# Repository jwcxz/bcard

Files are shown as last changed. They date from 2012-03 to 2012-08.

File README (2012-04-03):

bcard

http://jwcxz.com/projects/bcard

bcard is an experimental attempt to make cheap electronic business card on a
thin PCB.  The main goals are for it to be:

    - cheap
    - not gaudy
    - not stupid
    
As awesome as it would be to make the card appear as a USB flash device that
contains my resume, that would be a bit too expensive.  One alternative, is
this design:

    http://www.instructables.com/id/USB-PCB-Business-Card/
    
But somebody already made it :) Other designs are much more expensive.

    http://mikepuchol.com/my-pcb-business-card/
    http://electronoblog.allanw.org/2011/08/yet-another-pcb-business-card-with-touchpad/
    http://www.youtube.com/watch?v=gSN2SAgYy7M
    http://www.chasingtrons.com/main/tag/business-card
    
My design incorporates a capacitive touch sensor with some blue LEDs around the
corners.  The blue LEDs are actually mounted upside-down so that the card
fluoresces.

Cost of parts is about $1.80 in quantities of 25 (at Digi-Key prices).  At
quantities of 100, the cost per board is $1.54.  The majority of the cost is in
the 4 LEDs and the microcontroller.  You can shave off a few cents by going
with an ATTiny4 instead of an ATTiny10.

IDK, it's cute.

Software Used:
    Board Design: Kicad     http://kicad.sf.net
                  Inkscape  http://inkscape.org
    Firwmare:     AVRA      http://avra.sf.net
                  AVRDUDE   http://www.nongnu.org/avrdude/

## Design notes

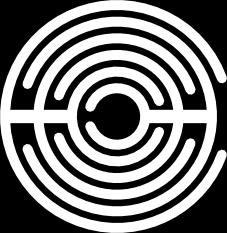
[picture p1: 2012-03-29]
imprint/sense.png

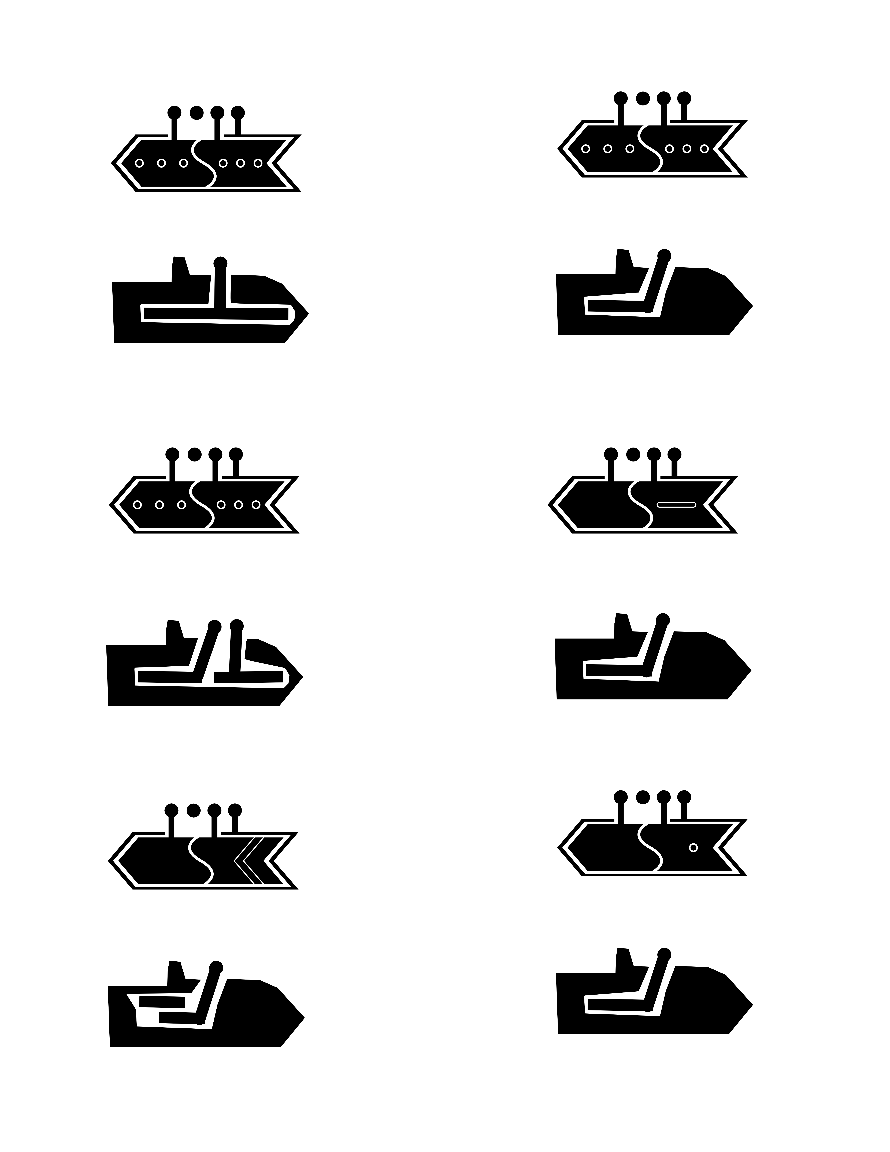
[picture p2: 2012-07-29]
boards/csensetests/csensetests2.png

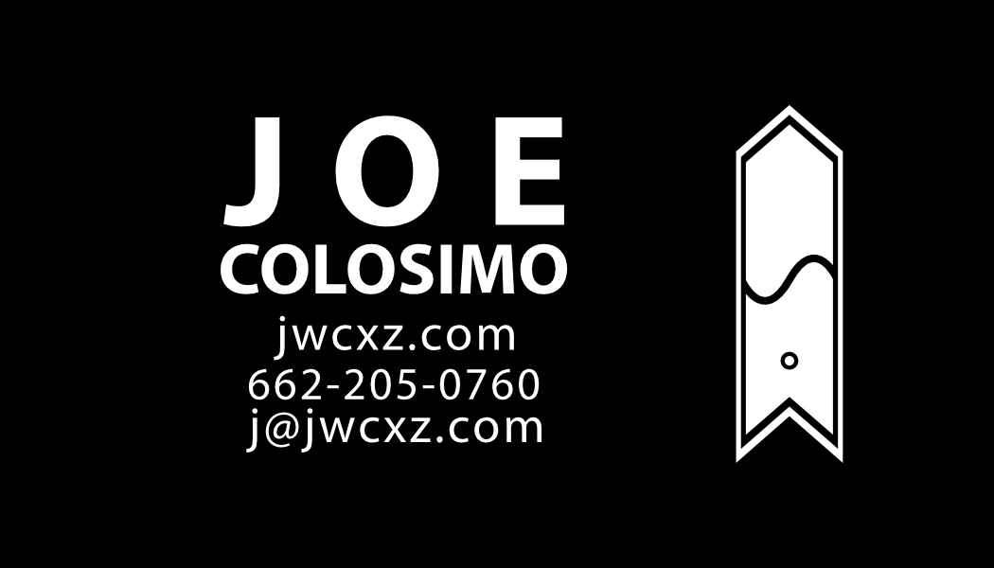
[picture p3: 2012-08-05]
imprint/swipesense.png

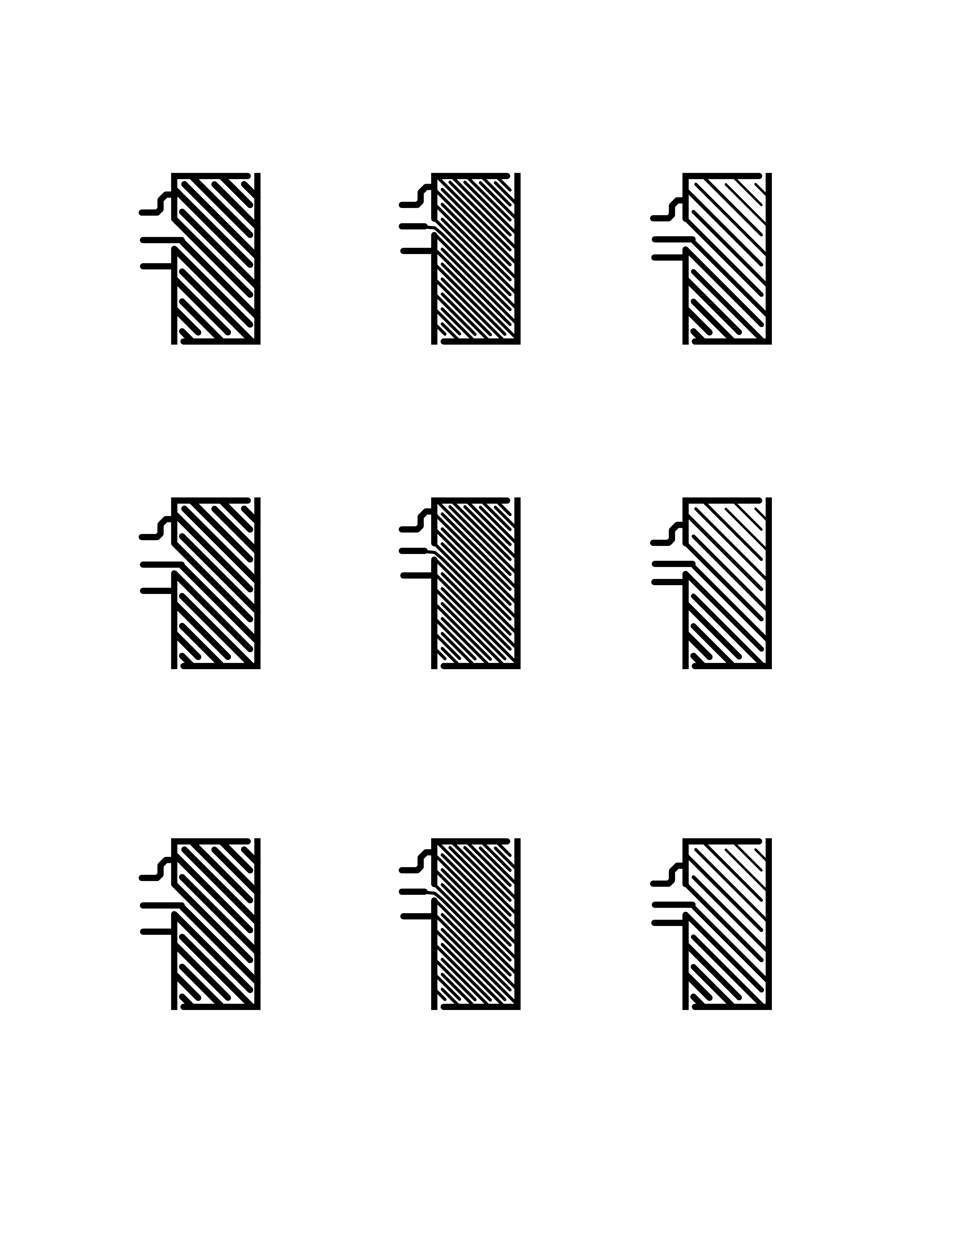
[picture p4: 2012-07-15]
boards/csensetests/csensetests.png

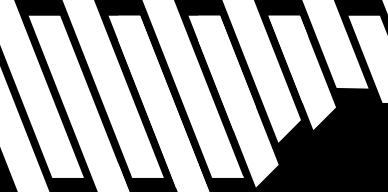
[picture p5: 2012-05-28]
imprint/sense2.png

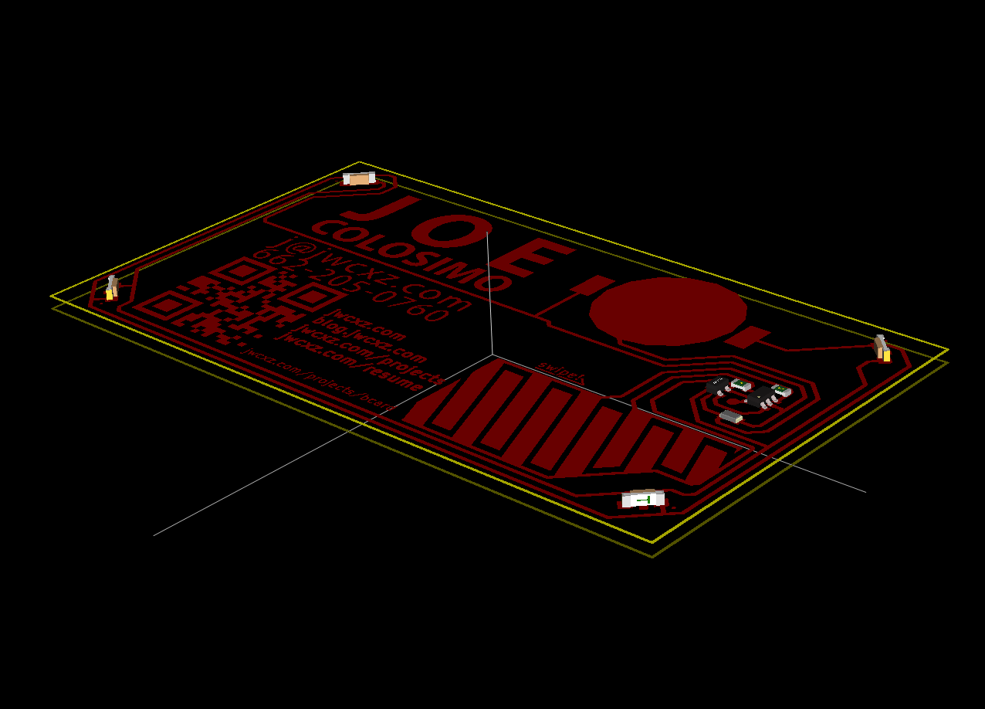
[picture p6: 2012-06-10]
boards/bcard/bcard-3d.png

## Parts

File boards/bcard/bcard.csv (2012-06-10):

ref | value | footprint | Field1 | Field2
C1 | 10uF | SM0805 | GRM21BR60J106KE19L | http://search.digikey.com/us/en/products/GRM21BR60J106KE19L/490-1717-1-ND/587426
D1 | LED | 1208vert | APT3216QBC/D | http://www.digikey.com/product-detail/en/APA3010QBC%2FD-GX/754-1582-1-ND/2757973
D2 | LED | 1208vert | APT3216QBC/D | http://www.digikey.com/product-detail/en/APA3010QBC%2FD-GX/754-1582-1-ND/2757973
D3 | LED | 1208vert | APT3216QBC/D | http://www.digikey.com/product-detail/en/APA3010QBC%2FD-GX/754-1582-1-ND/2757973
D4 | LED | 1208vert | APT3216QBC/D | http://www.digikey.com/product-detail/en/APA3010QBC%2FD-GX/754-1582-1-ND/2757973
IC1 | ATTINY10-TS | SOT23_6 | ATTINY10-TSHR | http://search.digikey.com/us/en/products/ATTINY10-TSHR/ATTINY10-TSHRCT-ND/2136158
K1 | CONN_3 | SENSOR2
LOGO1 | NAME | LOGO
LOGO2 | QRCODE | JWCXZ
P1 | BATT | 2032BATTHOLDER | BK-912 | http://www.digikey.com/product-detail/en/BK-912/BK-912-ND/2647825
P2 | CONN_1 | PAD
Q1 | BC846A | SOT323 | BC846A | http://search.digikey.com/us/en/products/BC846A,215/568-4866-1-ND/2122195
R1 | 1M | SM0603 | RC0603JR-071ML | http://search.digikey.com/us/en/products/RC0603JR-071ML/311-1.0MGRCT-ND/729625
R2 | 1M | SM0603 | RC0603JR-071ML | http://search.digikey.com/us/en/products/RC0603JR-071ML/311-1.0MGRCT-ND/729625

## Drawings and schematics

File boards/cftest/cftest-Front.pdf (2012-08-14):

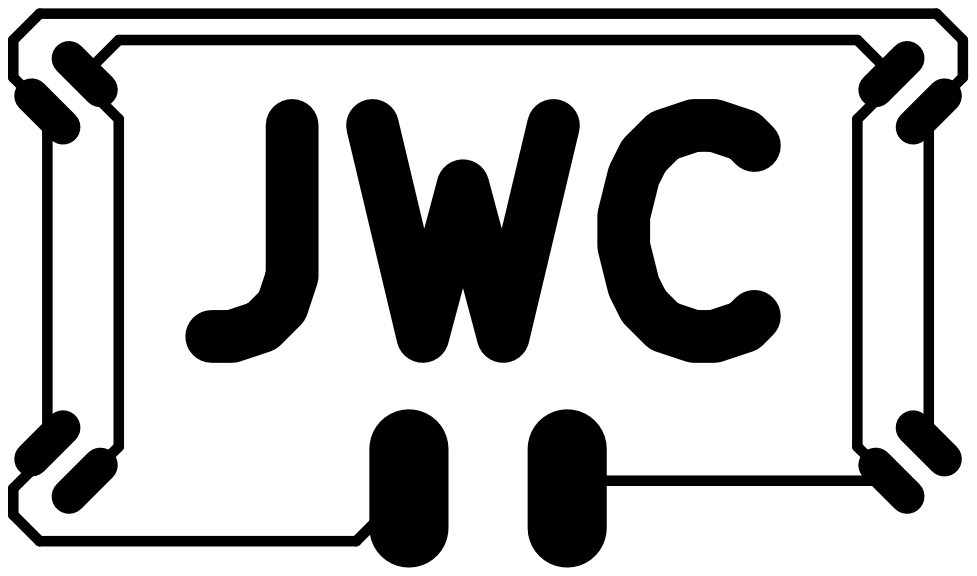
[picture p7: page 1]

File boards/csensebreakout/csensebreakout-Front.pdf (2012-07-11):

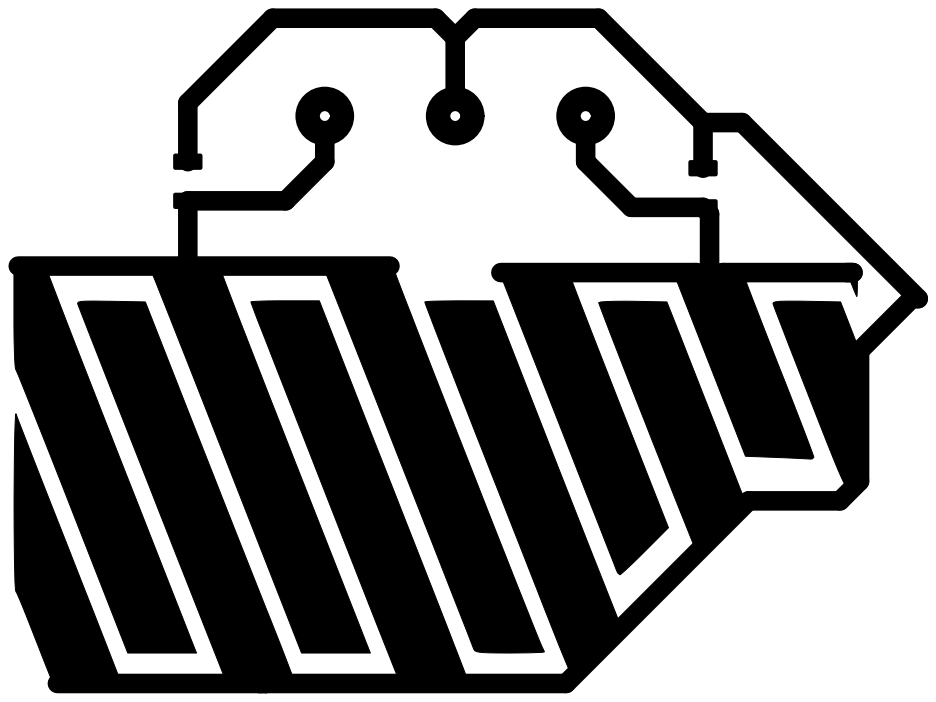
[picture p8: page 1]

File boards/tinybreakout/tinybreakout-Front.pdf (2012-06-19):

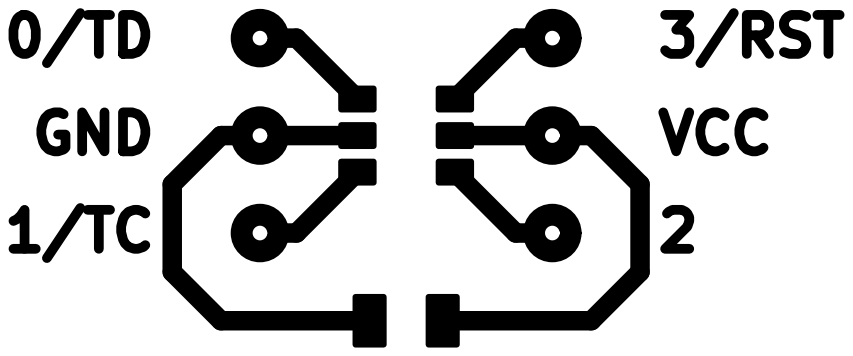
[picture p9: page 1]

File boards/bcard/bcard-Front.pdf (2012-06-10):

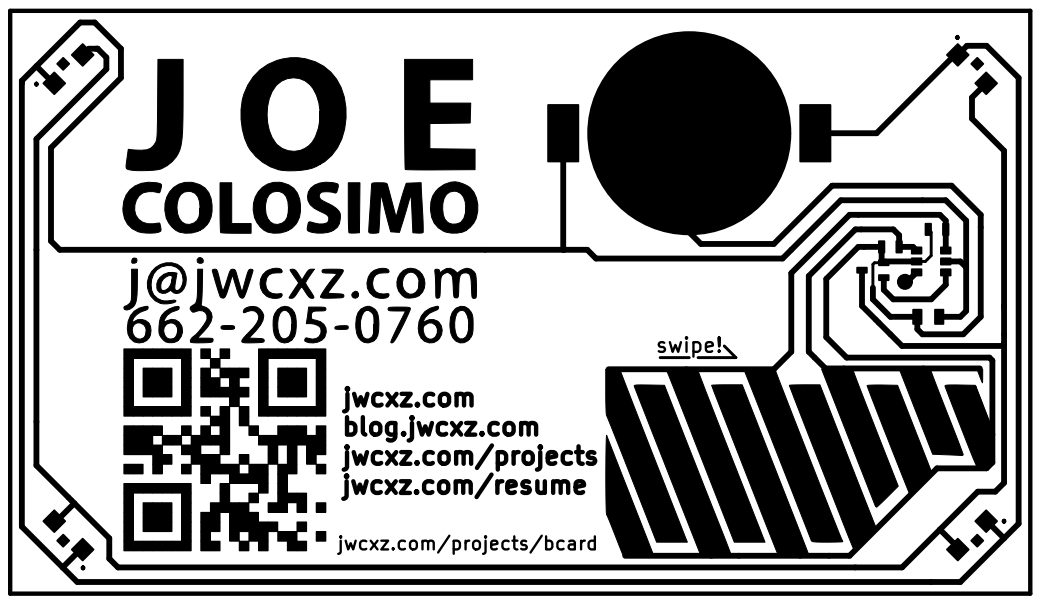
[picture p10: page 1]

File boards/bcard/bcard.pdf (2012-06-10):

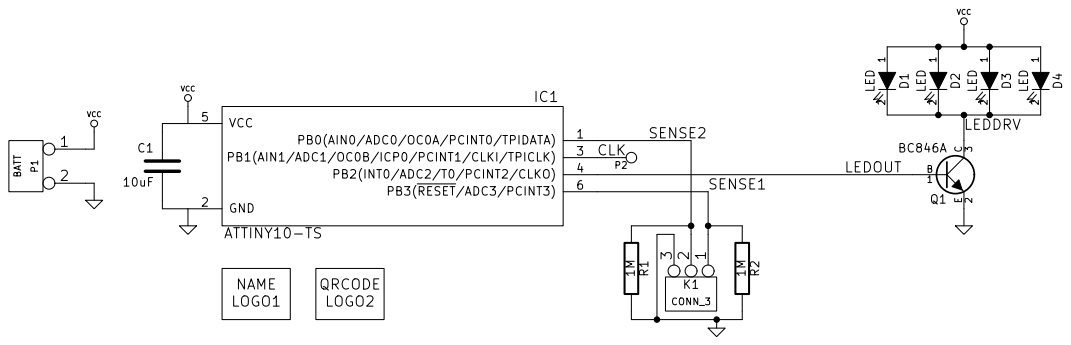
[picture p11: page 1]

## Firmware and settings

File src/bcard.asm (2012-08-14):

.DEVICE attiny10
.include "regs.inc"

.equ CFG_PWMLOOPS = 0x04

; register definitions
.def lthresh = r23
.def rthresh= r24
.def state = r25
.def ZH = r31
.def ZL = r30

; configurations that change
.equ CLKMSR_8MHZ = 0x00
.equ CLKMSR_128K = 0x01

; pin definitions
;.equ PIN_LED = 0
.equ PIN_LED = 0
.equ PIN_LFT = 1
.equ PIN_FDR = 1
.equ PIN_FLT = 2
.equ PIN_RGT = 0
;.equ PIN_RGT = 3

; capacitive touch sensor states
.equ ST_IDLE = 0
.equ ST_LEFT = 1
.equ ST_BOTH = 2

; sensor pressed values
.equ SNS_LEFT = 2   ; 10
.equ SNS_RGHT = 1   ; 01
.equ SNS_BOTH = 3   ; 11
.equ SNS_NONE = 0   ; 00

;-------------------------------------------------------

.cseg
.org 0x00
    rjmp reset
.org 0x01
    rjmp int0_interrupt
.org 0x08
    rjmp wdt_interrupt


reset: ; {{{
    ; clock setting: 
    ldi r16, CLKMSR_8MHZ

    ; apply clock settings
    ldi r17, 0xD8
    out CCP, r17
    out CLKMSR, r16

    ; set LED pin to be output
    sbi DDRB,  PIN_LED
    cbi PORTB, PIN_LED


    ; training phase
    ldi   r16, (1<<PIN_LFT)
    rcall cap_sense
    mov   r20, r17

    ldi   r16, (1<<PIN_RGT)
    rcall cap_sense
    mov   r21, r17

    ldi r19, 4
    train_loop:
        ; get left pin
        ldi   r16, (1<<PIN_LFT)
        rcall cap_sense

        ; average against existing
        lsr r20
        lsr r17
        add r20, r17


        ldi   r16, (1<<PIN_RGT)
        rcall cap_sense

        ; average against existing
        lsr r21
        lsr r17
        add r21, r17


        dec  r19
        brne train_loop


    ; define threshhold as 125% off value
    mov lthresh, r20
    lsr lthresh
    add lthresh, r20
    
    mov rthresh, r21
    lsr rthresh
    add rthresh, r21


    ; enable float driver to oscillate slowly
    rcall enable_float_driver

    ; start resistive sensing component
    sei

    ; TODO: sleep
    loop:
        rjmp loop
    ; }}}


enable_float_driver: ; {{{
    ; set floating input to 0
    cbi PUEB,  PIN_FLT
    cbi DDRB,  PIN_FLT
    cbi PORTB, PIN_FLT  ; TODO: not necessary

    ; enable floating driver
    sbi DDRB,  PIN_FDR

    ; ICR0 = 0x8000
    ldi r16, 0xFF
    ldi r17, 0xFF
    out ICR0H, r16
    out ICR0L, r17

    ; OCR0B = 0x4000
    ldi r16, 0x80
    ldi r17, 0x00
    out OCR0BH, r16
    out OCR0BL, r17

    ; set FAST PWM mode with ICR0 as TOP
    
    ; TCCR0A = COM0B0 | WGM01
    ldi r16, (1<<5) | (1<<1)
    out TCCR0A, r16

    ; TCCR0B = WGM03 | WGM02 | CS00
    ldi r16, (1<<4) | (1<<3) | (1<<0)
    out TCCR0B, r16

    ; enable interrupt mask
    sbi EIMSK, 0    ; INT0 on
    sbi EICRA, 0    ; ICS00 -- any change

    ret ; }}}


disable_float_driver: ; {{{
    ; shut off interrupt masks
    cbi EIMSK, 0

    ; shut off float driver and set as input
    ldi r16, 0
    out TCCR0A, r16
    out TCCR0B, r16
    cbi DDRB, PIN_FDR

    ret ; }}}


cap_sense: ; {{{
    ; in : r16 - sensor to use
    ; out: r16 - pressed or unpressed
    ;      r17 - counter value
    ; f-u: r18

    mov r17, r16
    ori r17, (1<<PIN_LED)   ; DDR needs LED output on too

    ; drive sensor
    out DDRB, r17       ; DDR: outputs are (LED | sensor)
    out PORTB, r16      ; drive sensor

    ; TODO: delay?
    rcall delay_short

    ldi r17, (1<<PIN_LED)   ; switch to sensor input
    out DDRB, r17
    ldi r17, 0              ; shut sensor driver off
    out PORTB, r17
    ; TODO: anything needed for PUEB?

    ; now, loop, waiting for the sensor to fall

    cap_sense_check_loop:
        ; mask against pin
        in  r18, PINB
        and r18, r16

        ; if pin is 0, then break out of the loop
        breq cap_sense_check_loop_dn

        ; else add 1 to the counter
        inc r17

        ; check if we've hit the max
        ; if so, get out of the loop
        cpi r17, 0xFF
        brne cap_sense_check_loop

    cap_sense_check_loop_dn:

    ; figure out which pin's threshold to compare against
    cpi  r16, (1<<PIN_LFT)
    mov  r18, lthresh
    breq compare
    mov  r18, rthresh

    compare:
    cp   r17, r18
    brsh cap_sense_pin_on
        ldi  r16, 0
        ret

    cap_sense_pin_on:
        ldi r16, 1
        ret
    ; }}}


delay_long: ; {{{
    ldi r28, 0x10
    rjmp dly2

delay_short:
    ldi r28, 0x01
    ldi r27, 0x05
    rjmp dly1

delay_reallylong:
    ldi r28, 0xFF
    rjmp dly2

dly2:
    ldi r27, 0xFF
    dly1:
        dec r27
        brne dly1

    dec r28
    brne dly2

    ret ; }}}


int0_interrupt: ; {{{
    rcall disable_float_driver

    ; now that we've hit an interrupt, it's time to detect a swipe

    ldi state, ST_IDLE

    int0_sense_loop:
        ldi r16, (1<<PIN_LFT)
        rcall cap_sense

        ; copy left sensor state to r19,20
        mov r19, r16
        mov r20, r17

        ldi r16, (1<<PIN_RGT)
        rcall cap_sense

        lsl r19         ; shift left is_on over
        or  r16, r19    ; or it with right
        ; so, r16 contains one of SNS_LEFT, SNS_RGHT, SNS_BOTH, or SNS_NONE

        ; the state machine looks at the is_on values (stored in bits 1 and 0
        ; of r16 ; for left and right sensors respectively) and determines the
        ; swipe status from there
        ; based on the current algorithm, it could really just be boiled down
        ; to like just a latch, but whatever
        sm_chk_idle:
            cpi  state, ST_IDLE
            brne sm_chk_left
            ; if we're in the idle state, that means that we haven't done anything yet

            ; XXX: I'm pretty sure this can be folded into ST_LEFT; the
            ;      original idea was for it to only be able to occur once

            ; transition mappings
            ; sns | new_state
            ; ----|----------
            ;  00 | *halt*
            ;  01 | ST_LEFT
            ;  10 | *halt*
            ;  11 | ST_BOTH

            sm_idle_chk_left:
                cpi  r16, SNS_LEFT
                brne sm_idle_chk_both
                ldi  state, ST_LEFT
                rjmp int0_sense_loop_end

            sm_idle_chk_both:
                cpi  r16, SNS_BOTH
                brne int0_dn
                ldi  state, ST_BOTH
                rjmp int0_sense_loop_end


        sm_chk_left:
            cpi  state, ST_LEFT
            brne sm_chk_both

            ; transition mappings
            ; sns | new_state
            ; ----|----------
            ;  00 | *halt*
            ;  01 | ST_LEFT
            ;  10 | *halt*
            ;  11 | ST_BOTH

            sm_left_chk_both:
                cpi  r16, SNS_BOTH
                brne sm_left_chk_left
                ldi  state, ST_BOTH
                rjmp int0_sense_loop_end

            sm_left_chk_left:
                cpi  r16, SNS_LEFT
                brne int0_dn
                rjmp int0_sense_loop_end


        sm_chk_both:
            cpi state, ST_BOTH
            brne int0_dn        ; wtf!?!?!?!?
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

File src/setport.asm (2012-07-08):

.DEVICE attiny10
.include "regs.inc"

rjmp RESET  ;go and set up PORTB as an output 


;name registers (selected >r15 arbitrarily)
.def  counter1  = r16
.def  counter2  = r17
.def  counter3  = r18 


;set some variables 
;time1 and time2 set the value for the final loop in each delay
.equ  time1   = 170 ;between 0 and 255
.equ  time2   = 1
.equ  led     = 2 ;LED at PB2 

RESET: ;set PB2 as an output in the Data Direction Register for PORTB
sbi   DDRB, led  ;connect LED to PB2 (Attiny10 pin 4)

flash: ;main loop  
sbi PORTB, led
cbi PORTB, led
rjmp flash


;;cbi   PORTB, led ;LED off - cbi/sbi swapped for N-FET switching (ie.LED is OFF when FET is ON)
;ldi   r17, 170 ;load counter1 delay         
;rcall onDelay            
;;sbi   PORTB, led ;LED on           
;ldi   r18, 1 ;load counter3 delay
;rcall offDelay
;rjmp  flash  ;return to beginning of loop
;
;
;onDelay:       
;clr   r16  ;clear counter1 
;
;
;loop1: ;nested loop that decrements counter 1 (255) x counter2 (time1) times (ie. 255*time1)
;dec   r16  ;decrement counter1 
;brne  loop1     ;branch if not 0     
;dec   r17  ;decrement counter2 
;brne  loop1     ;branch if not 0     
;ret      
;
;offDelay: ;same as onDelay but with a third loop     
;clr   r16
;clr   r17 
;
;
;loop2: ;decrement counter 1(255) x counter2(255) x counter3(time2) (ie. 255*255*time2) 
;dec   r16
;brne  loop2         
;dec   r17
;brne  loop2          
;dec   r18 
;brne  loop2 
;ret     
;
;lds r15, 128

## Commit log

2012-03-04 started board
    [bcard.brd]
2012-03-06 added some qr codes, playing around with various ideas
    [$savepcb.brd]
2012-03-09 first attempt at a layout -- very rough
    [$savepcb.brd, bcard.brd, bcard.csv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]
2012-03-10 working on layout
    [$savepcb.brd, bcard.brd]
2012-03-29 first potential design ready -- needs etching
    [bcard.brd, bcard.csv, bcard.sch]
2012-03-29 first pcb design basically done
    [bcard.brd, bcard.csv, bcard.sch]
2012-04-06 changed outer track widths to 20 mils for more reliable etching.
    [bcard.brd]
2012-04-22 working on new board design
    [bcard.brd]
2012-05-25 attempt at modified LEDs
    [bcard.brd]
2012-05-28 almost done with new style
    [bcard.brd, bcard.sch]
2012-05-28 finished next revision of bcard -- ready to etch
    [bcard.brd, bcard.sch]
2012-05-30 revision 1.2 ready for etching -- uses a battery clip and side-oriented LEDs
    [bcard.brd, bcard.sch]
2012-06-08 cleaned up board for etching -- successful etch confirmed
    [bcard.brd]
2012-06-10 3rd design export -- I really need to create a makefile for this...
    [bcard.brd, bcard.csv, bcard.sch]
2012-06-19 added attiny10 breakout board
    [tinybreakout.brd, tinybreakout.sch]
2012-07-10 whoops, that was supposed to be SOT23 for the transistor, not SOT323
    [bcard.brd]
2012-07-11 added breakout board for the cap sensor -- maybe we need to make it thinner traces
    [csensebreakout.brd, csensebreakout.sch]
2012-07-11 atmega testing framework for capacitive sensing algos built
2012-07-15 added a couple of test patterns in preparation for complete board redesign
2012-07-16 first pass at an averaging algo... does not work
    [main.c, plot.py]
2012-07-22 trying the derpy floating pin sensor board :/
2012-07-27 hopefully the actual final version of the sensor test -- uses double sided board to achieve floating pins
2012-07-28 revision of double layer sensor board test
2012-07-28 working algorithm for sensing (no power management)
2012-07-28 new swipe sensor for final bcard layout
2012-07-29 switching to dual layer board
    schematics and netlist are correct (and even annotated!)
    board layout needs serious work
    sensor might change a little bit
    gahhhhhhhhhhhhhhhhhh
    [bcard.brd, bcard.sch]
2012-08-05 cleaned up csense.asm, bcard.asm does its thing correctly (needs pwm)
    [bcard.asm, csense.asm]
2012-08-06 basic algo working -- needs some tweaking, pin reassignment, and power optimization
2012-08-07 code cleanup in preparation for pin switch
2012-08-14 added test of conformal coating
    [cftest.brd, cftest.sch]
